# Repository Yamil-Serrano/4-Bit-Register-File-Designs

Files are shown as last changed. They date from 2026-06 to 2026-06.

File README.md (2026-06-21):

# 4-Bit Register File Designs

A collection of 4-bit register file implementations
exploring architectural trade-offs between
hardware minimalism and full register flexibility.
These designs demonstrate how storage, decoding,
and multiplexing interact inside a CPU register file
using discrete logic ICs and explicit wiring.

This repository includes two complete register file
architectures: a minimalist split-read design using
74HC157 multiplexers, and a fully flexible design
using 74HC153 multiplexers. Together, they show how
architectural decisions directly affect hardware
complexity, wiring density, and instruction freedom.

# Minimalist 4-Bit Register File (RB1574B – Split Read Architecture)

RB1574B represents a hardware-minimalist approach
to register file design. It is built entirely
from discrete logic ICs and focuses on reducing
the number of multiplexers required for register
selection while maintaining full write capability.

The architecture uses a split read model, where
each read port accesses a different subset of
registers. This limits some register-to-register
operations but significantly reduces hardware
complexity and control logic.

## Technical Specifications

### Core Features

* **Register Count**: 4 general-purpose registers
* **Register Width**: 4-bit parallel storage
* **Storage Type**: Edge-triggered D-type flip-flops
* **Read Ports**:

  * RS1: Register 1 or Register 2
  * RS2: Register 3 or Register 4
* **Write Port**: Single global RegWrite signal
* **Clocked Write**: Yes

## Integrated Circuits Used

| IC | Function | Quantity | Purpose |
| --- | --- | --- | --- |
| **74HC173** | 4-bit D-type Register | 4 | Register storage |
| **74HC157** | 2:1 Multiplexer | 2 | Read path selection |
| **74HC238** | 3-to-8 Decoder | 1 | Register write decoding |
| **74HC00**  | Quad NAND Gate | 1 | RegWrite gating logic |

## Hardware Implementation

### Circuit Design
Main

## Architecture Details

### Read Operation

* RS1 selects between Register 1 and Register 2
* RS2 selects between Register 3 and Register 4
* Registers within the same group cannot be read together
* Cross-group operations are supported

This split read structure mirrors constrained or
early CPU designs where hardware limitations
shape instruction-level flexibility.

### Write Operation

* A 74HC238 decoder selects one register
* NAND gates combine decoder outputs with RegWrite
* Only the selected register is enabled for writing
* Write access is fully flexible across all registers

### Breadboard Implementation


## Design Philosophy

RB1574B prioritizes simplicity and hardware efficiency.
By limiting read flexibility, the design reduces
chip count, wiring density, and control complexity.
This architecture demonstrates how physical hardware
constraints directly influence CPU behavior.

## Known Limitations

1. Not all register-to-register combinations are possible
2. RS1 and RS2 access disjoint register groups
3. Additional data movement instructions may be required

# Full 4-Bit Register File (RB1534B – Complete Read Architecture)

RB1534B represents a fully flexible register file implementation. Both read ports can independently access any register, enabling all possible register-to-register operations in hardware. This completeness comes at the cost of increased multiplexing logic, dense wiring, and higher visual complexity, especially in discrete IC designs.

### Core Features

- **Register Count**: 4 general-purpose registers
- **Register Width**: 4-bit parallel storage
- **Storage Type**: Edge-triggered D-type flip-flops
- **Read Ports**: Two fully independent read outputs
- **Write Port**: Single global RegWrite signal
- **Clocked Write**: Yes

### Integrated Circuits Used

| IC | Function | Quantity | Purpose |
| --- | --- | --- | --- |
| **74HC173** | 4-bit D-type Register | 4 | Register storage |
| **74HC153** | Dual 4:1 Multiplexer | 4 | Full read selection |
| **74HC238** | 3-to-8 Decoder | 1 | Register write decoding |
| **74HC00** | Quad NAND Gate | 1 | RegWrite gating logic |

**Total Components**: 10 ICs, implementing a complete 4-bit register file with full read/write flexibility.

## Hardware Implementation

### Circuit Design
Main_1

### PCB Design in KiCad


After validating the architecture in simulation, the design was migrated from breadboard to a custom PCB manufactured via JLCPCB. Each IC is paired with a dedicated 100nF ceramic bypass capacitor placed directly at the power pins to suppress switching noise. A 100µF bulk electrolytic capacitor stabilizes the 5V supply rail.

### Physical Build


## Verification & Test Bench

To validate correct operation across all possible register file states, a dedicated test bench was developed using an ESP32 microcontroller. The [`firmware`](./src/tester/src) exhaustively tests all register read/write combinations. Due to I/O pin limitations on the ESP32, the two read ports (RS1 and RS2) could not be tested simultaneously. Instead, a sequential verification strategy was employed:

- **RS1 Validation**: First, all register read/write combinations were exhaustively tested using Read Port 1 (RS1). Every possible write pattern (0–15) was written to each of the 4 registers, and RS1 independently selected each register to verify output correctness.
- **RS2 Validation**: After confirming 100% correct operation of RS1, the same test harness was reconfigured (pins reassigned) to validate Read Port 2 (RS2) identically.
- **Write Verification**: Writes a unique 4-bit pattern (0–15) to each of the 4 registers across multiple cycles.
- **Independence Test**: Verifies that writing to one register does not affect the contents of other registers.
- **RegWrite Gating**: Ensures that when RegWrite is low, no register state changes occur.

A total of 2,048 possible register file states (4 registers × 16 values × 16 read combinations for each port) were tested per read port, with both ports passing with 100% accuracy. Results are reported over Serial with ANSI color coding, distinguishing passing tests in green from failures in red. A 20×4 LCD display connected via I2C provides a real-time progress bar during testing and a summary screen upon completion.

### Operation Details

#### 1. **Register Write Operation**

- Write address decoded via 74HC238 3-to-8 decoder
- RegWrite signal gated with clock edge using 74HC00 NAND logic
- Data applied to all 74HC173 registers, but only selected register accepts new value on clock edge

#### 2. **Register Read Operation – Port 1 (RS1)**

- 2× 74HC153 multiplexers select any of the 4 registers
- 2-bit RS1 address selects which register appears on Read Data 1 bus

#### 3. **Register Read Operation – Port 2 (RS2)**

- Independent 2× 74HC153 multiplexer bank (separate from RS1)
- 2-bit RS2 address selects any register for Read Data 2 bus
- Both read ports operate simultaneously with zero contention

## Design Philosophy

RB1534B prioritizes architectural completeness over hardware simplicity. Every register selection is explicitly decoded and multiplexed, making this design ideal for studying scalable CPU register files and data-path construction.

## Comparative Summary

| Feature | RB1574B | RB1534B |
| --- | --- | --- |
| Read Flexibility | Limited (2×2) | Full (4×4) |
| Write Flexibility | Full | Full |
| Chip Count | Low | High |
| Wiring Density | Low | Very High |
| Educational Focus | Constraints | Completeness |

# FPGA Implementation: 4-Bit Register File (Tang Nano 9K)

This module implements a 4-bit register file on the Sipeed Tang Nano 9K FPGA, translating a discrete, flip-flop–based register file into a compact HDL description. The design faithfully recreates a classic hardware register file built from D flip-flops, a 2-to-4 decoder, and external multiplexers, preserving the original architectural intent while leveraging FPGA integration. The register file serves as a foundational storage element for a CPU-style datapath, providing controlled write access and multiple read paths suitable for ALU operand sourcing.

## Physical Prototype & Interfacing

To maintain a hands-on and educational workflow, the FPGA is interfaced with external switches and LEDs, closely mirroring the behavior and observability of the original discrete implementation.

**Input (Switches):**

* A 4-bit switch group provides *speculative ALU data*, allowing manual injection of values into the register file.
* Additional switches select the write register address and control the global write enable (`RegWrite`).
* All inputs use pull-down configurations to guarantee stable logic levels and avoid floating inputs.

**Output (LEDs):**

* Two independent 4-bit LED groups display the contents of the selected source registers (`rs1` and `rs2`).
* LEDs operate in an active-high configuration, where illumination represents a logic high (`1`).

This interface allows direct visual confirmation of register contents and write/read behavior in real time.

20251222\_233541
*Tang Nano 9K demonstrating manual register writes and LED-based readout.*

## Design Philosophy & Notes

* **Discrete-to-HDL Fidelity**: The register file was intentionally described using explicit registers, a decoder, and multiplexers to mirror the original TTL-based design (e.g., 74HC238 for decoding and 74HC157 for selection), rather than relying on abstract HDL shortcuts.
* **Educational Transparency**: Each register is represented explicitly, making the data flow and control logic easy to trace and reason about, especially for learners transitioning from breadboard-based designs to HDL.
* **Controlled Write Semantics**: A global write enable combined with a decoded register select ensures that exactly one register captures data on a rising clock edge, replicating real-world register file behavior.
* **Modular Expansion**: Exposing individual register outputs enables flexible experimentation, such as external multiplexing, debugging, or future ALU integration.

## Comparative Summary: Discrete vs. FPGA Register File

| Aspect | Discrete IC Implementation | FPGA Implementation |
| :--- | :--- | :--- |
| **Component Count**  | Multiple flip-flops, decoder, and multiplexers. | **1** FPGA device. |
| **Storage Elements** | Individual 74HC173 wired by hand. | Synthesized registers from HDL. |
| **Address Decoding** | Physical 74HC238 decoder IC. | Behavioral decoder logic. |
| **Read Selection** | External multiplexers (e.g., 74HC157). | Combinational HDL multiplexing. |
| **Flexibility** | Fixed wiring; modifications require rewiring. | **Reconfigurable** via HDL changes. |
| **Learning Focus** | Understanding register-level hardware construction. | Bridging discrete logic concepts into FPGA-based design. |

### Historical Note:

While working on this design, I later discovered the 74HC670, a single IC that could implement a full 4-bit register file with all read/write flexibility. At that point, I had already spent around $35 on multiple ICs (157s, 153s, 173s, etc.) to build the RB157 and RB153 designs, while the 74HC670 costs around $10. However, building the register files with discrete components first gave me deep insight into MUX cascading, RegWrite logic, and architectural limitations.

Reflection: If I had bought the 74HC670 from the start:

* I would not have understood MUX cascades
* I would not have understood RegWrite
* I would not have seen real limitations
* The chip would have been a black box

With $10 you could buy a fully functional chip. With $35, you bought deep understanding and hands-on experience.

## License

Licensed under the **Solderpad Hardware License v2.1**.
See the [LICENSE](LICENSE-HARDWARE) file for full terms.

## Contact

If you have any questions or suggestions, feel free to reach out:

* **GitHub:** [Neowizen](https://github.com/Yamil-Serrano)

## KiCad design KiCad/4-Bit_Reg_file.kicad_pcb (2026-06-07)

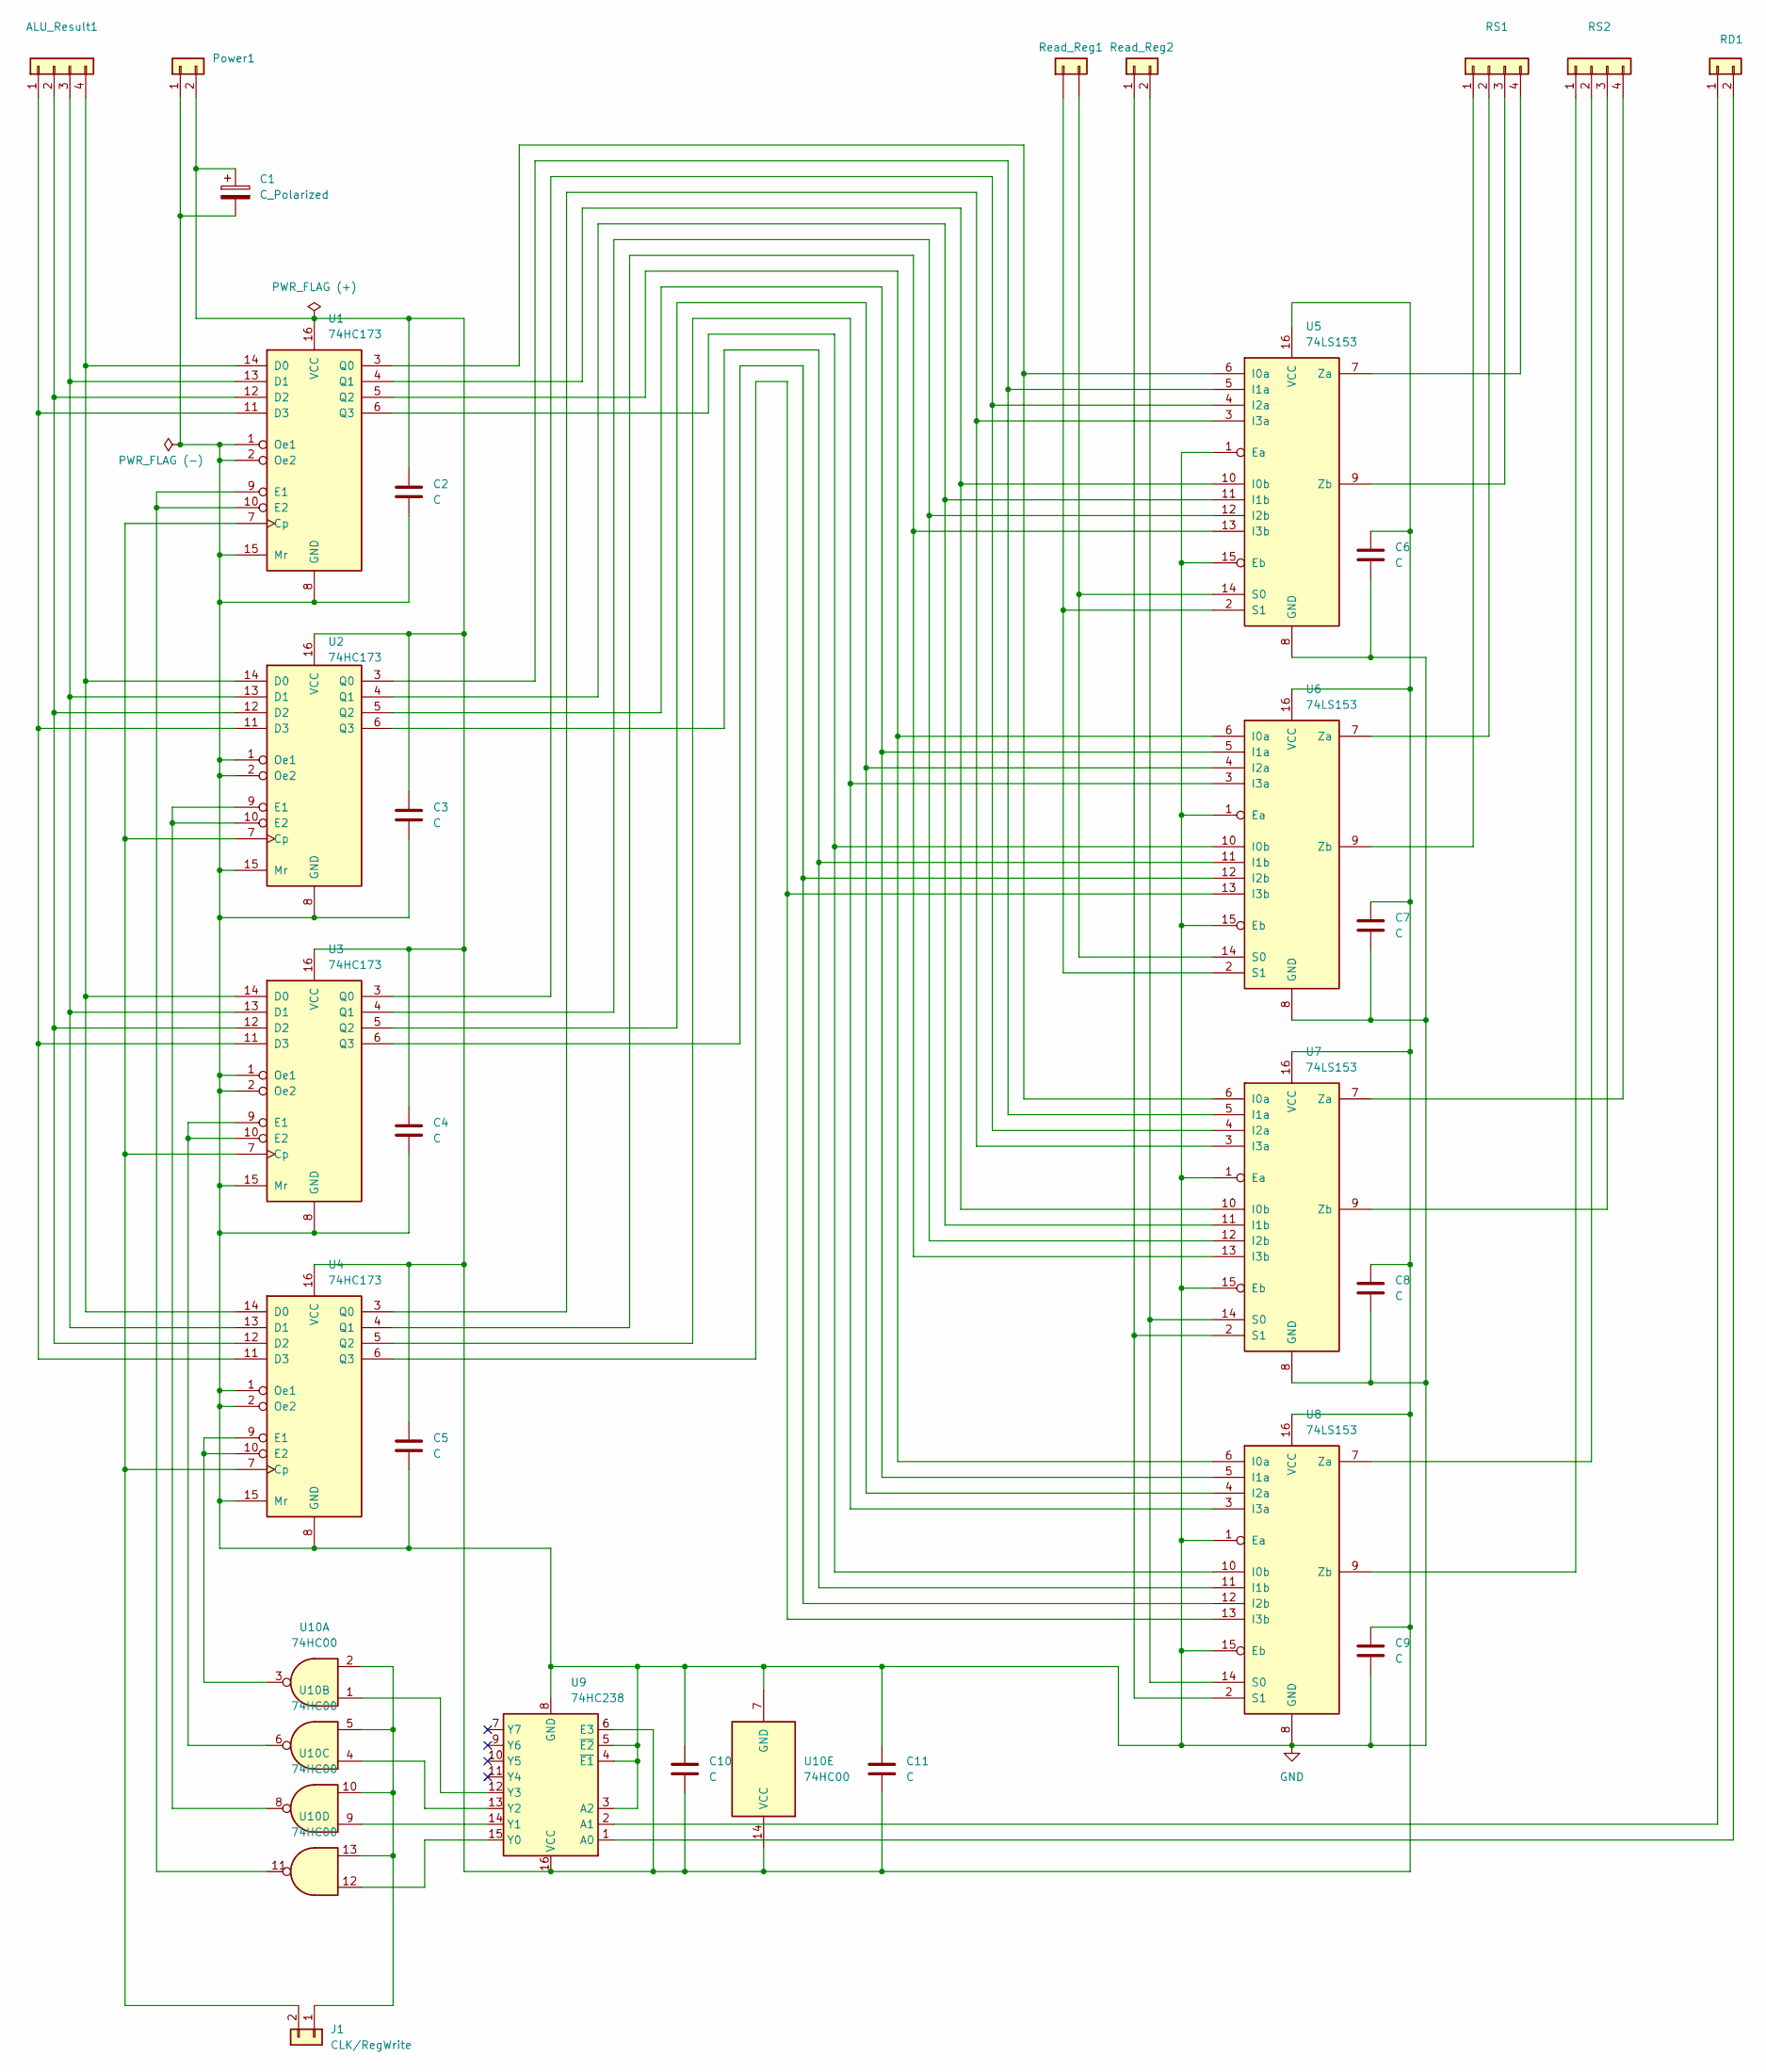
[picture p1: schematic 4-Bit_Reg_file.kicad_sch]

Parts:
ALU_Result1: Conn_01x04; PinHeader_1x04_P2.54mm_Vertical
C1: C_Polarized; CP_Radial_D4.0mm_P1.50mm
C2, C3, C4, C5, C6, C7, C8, C9, C10, C11: C; C_Disc_D3.0mm_W1.6mm_P2.50mm
J1: CLK/RegWrite; PinHeader_1x02_P2.54mm_Vertical
Power1: Conn_01x02; PinHeader_1x02_P2.54mm_Vertical
RD1: Conn_01x02; PinHeader_1x02_P2.54mm_Vertical
RS1, RS2: Conn_01x04; PinHeader_1x04_P2.54mm_Vertical
Read_Reg1, Read_Reg2: Conn_01x02; PinHeader_1x02_P2.54mm_Vertical
U1, U2, U3, U4: 74HC173; DIP-16_W7.62mm_Socket
U5, U6, U7, U8: 74LS153; DIP-16_W7.62mm_Socket
U9: 74HC238; DIP-16_W7.62mm_Socket
U10: 74HC00; DIP-14_W7.62mm_Socket

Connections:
GND: C1.2, C2.2, C3.2, C4.2, C5.2, C6.2, C7.2, C8.2, C9.2, C10.1, C11.1, Power1.1, U1.1 (Oe1), U1.2 (Oe2), U1.8 (GND), U1.15 (Mr), U2.1 (Oe1), U2.2 (Oe2), U2.8 (GND), U2.15 (Mr), U3.1 (Oe1), U3.2 (Oe2), U3.8 (GND), U3.15 (Mr), U4.1 (Oe1), U4.2 (Oe2), U4.8 (GND), U4.15 (Mr), U5.1 (Ea), U5.8 (GND), U5.15 (Eb), U6.1 (Ea), U6.8 (GND), U6.15 (Eb), U7.1 (Ea), U7.8 (GND), U7.15 (Eb), U8.1 (Ea), U8.8 (GND), U8.15 (Eb), U9.3 (A2), U9.4 (~E1), U9.5 (~E2), U9.8 (GND), U10.7 (GND)
unnamed: ALU_Result1.1, U1.11 (D3), U2.11 (D3), U3.11 (D3), U4.11 (D3)
unnamed: ALU_Result1.2, U1.12 (D2), U2.12 (D2), U3.12 (D2), U4.12 (D2)
unnamed: ALU_Result1.3, U1.13 (D1), U2.13 (D1), U3.13 (D1), U4.13 (D1)
unnamed: ALU_Result1.4, U1.14 (D0), U2.14 (D0), U3.14 (D0), U4.14 (D0)
unnamed: J1.1, U10.2, U10.5, U10.10, U10.13
unnamed: J1.2, U1.7 (Cp), U2.7 (Cp), U3.7 (Cp), U4.7 (Cp)
unnamed: C1.1, C2.1, C3.1, C4.1, C5.1, C6.1, C7.1, C8.1, C9.1, C10.2, C11.2, Power1.2, U1.16 (VCC), U2.16 (VCC), U3.16 (VCC), U4.16 (VCC), U5.16 (VCC), U6.16 (VCC), U7.16 (VCC), U8.16 (VCC), U9.6 (E3), U9.16 (VCC), U10.14 (VCC)
unnamed: RD1.1, U9.2 (A1)
unnamed: RD1.2, U9.1 (A0)
unnamed: RS1.1, U6.9 (Zb)
unnamed: RS1.2, U6.7 (Za)
unnamed: RS1.3, U5.9 (Zb)
unnamed: RS1.4, U5.7 (Za)
unnamed: RS2.1, U8.9 (Zb)
unnamed: RS2.2, U8.7 (Za)
unnamed: RS2.3, U7.9 (Zb)
unnamed: RS2.4, U7.7 (Za)
unnamed: Read_Reg1.1, U5.2 (S1), U6.2 (S1)
unnamed: Read_Reg1.2, U5.14 (S0), U6.14 (S0)
unnamed: Read_Reg2.1, U7.2 (S1), U8.2 (S1)
unnamed: Read_Reg2.2, U7.14 (S0), U8.14 (S0)
unnamed: U1.9 (E1), U1.10 (E2), U10.11
unnamed: U1.3 (Q0), U5.6 (I0a), U7.6 (I0a)
unnamed: U1.4 (Q1), U5.10 (I0b), U7.10 (I0b)
unnamed: U1.5 (Q2), U6.6 (I0a), U8.6 (I0a)
unnamed: U1.6 (Q3), U6.10 (I0b), U8.10 (I0b)
unnamed: U2.9 (E1), U2.10 (E2), U10.8
unnamed: U2.3 (Q0), U5.5 (I1a), U7.5 (I1a)
unnamed: U2.4 (Q1), U5.11 (I1b), U7.11 (I1b)
unnamed: U2.5 (Q2), U6.5 (I1a), U8.5 (I1a)
unnamed: U2.6 (Q3), U6.11 (I1b), U8.11 (I1b)
unnamed: U3.9 (E1), U3.10 (E2), U10.6
unnamed: U3.3 (Q0), U5.4 (I2a), U7.4 (I2a)
unnamed: U3.4 (Q1), U5.12 (I2b), U7.12 (I2b)
unnamed: U3.5 (Q2), U6.4 (I2a), U8.4 (I2a)
unnamed: U3.6 (Q3), U6.12 (I2b), U8.12 (I2b)
unnamed: U4.9 (E1), U4.10 (E2), U10.3
unnamed: U4.3 (Q0), U5.3 (I3a), U7.3 (I3a)
unnamed: U4.4 (Q1), U5.13 (I3b), U7.13 (I3b)
unnamed: U4.5 (Q2), U6.3 (I3a), U8.3 (I3a)
unnamed: U4.6 (Q3), U6.13 (I3b), U8.13 (I3b)
unnamed: U9.15 (Y0), U10.12
unnamed: U9.14 (Y1), U10.9
unnamed: U9.13 (Y2), U10.4
unnamed: U9.12 (Y3), U10.1

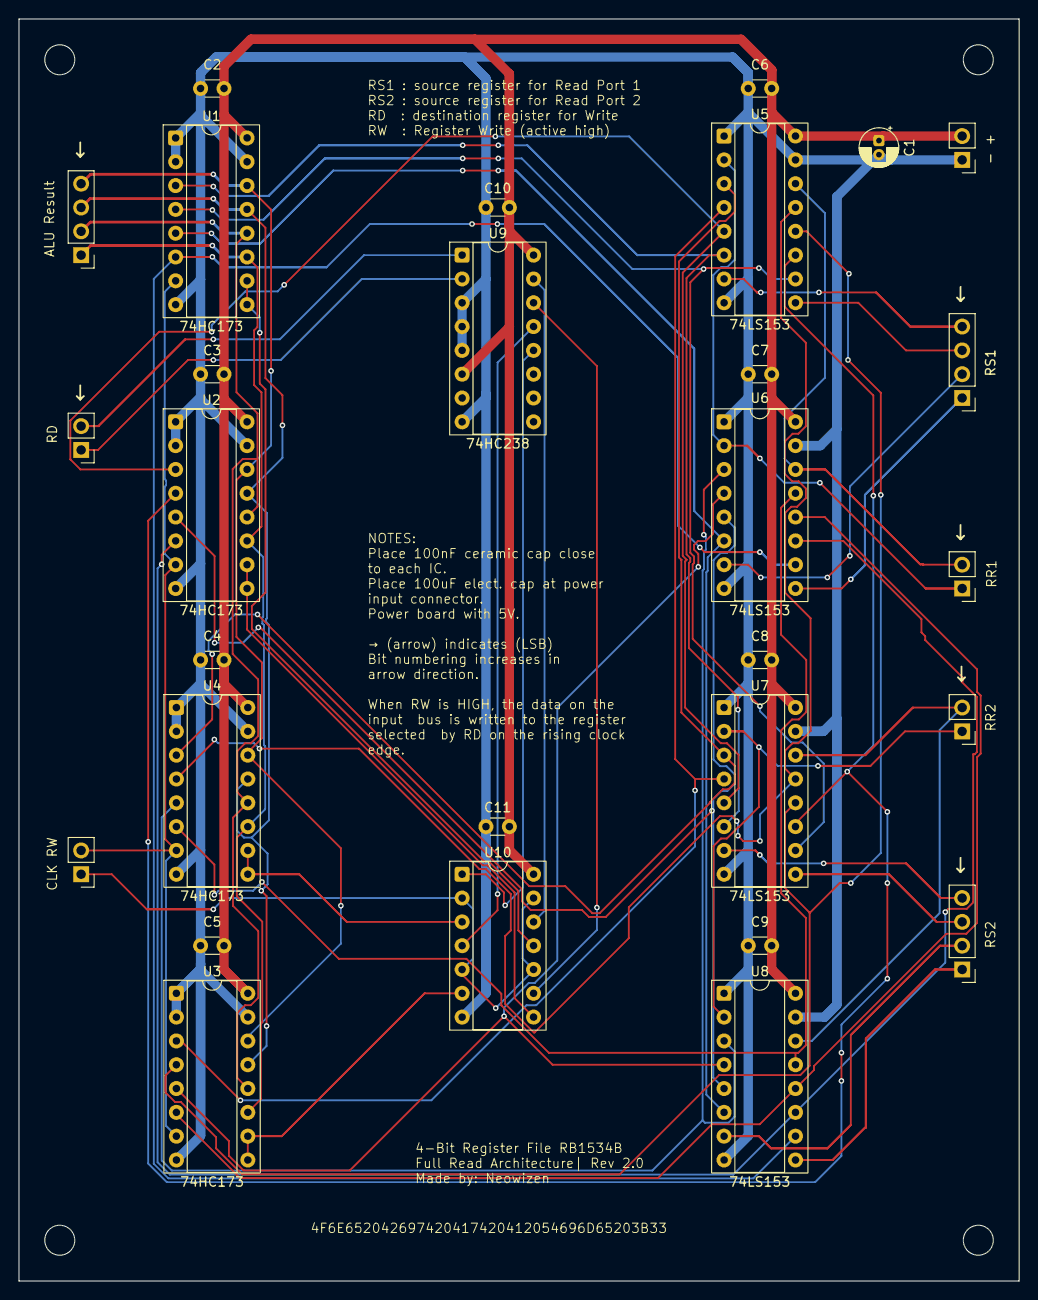
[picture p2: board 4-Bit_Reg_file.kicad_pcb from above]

Board: 2 copper layers, 106.7 x 134.6 mm, 29 parts (0 on the bottom side), 46 nets.

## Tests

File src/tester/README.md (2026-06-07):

# 4-Bit ALU Tester for ESP32

## Upload Instructions

### Windows
Just upload your code. That's it. No additional configuration needed.

### Linux
**One-time setup (do this once):**

1. Run: sudo usermod -a -G dialout $USER
2. Restart your computer

**After setup:** upload normally with pio run --target upload

## Monitor Output
Run: pio device monitor
Press Ctrl + C to exit.

## Folder Structure
Your .cpp file must be inside the src/ folder.

## Common Errors
- **"Permission denied: /dev/ttyUSB0" on Linux** → You skipped the one-time setup. Add yourself to dialout group and restart.

- **"undefined reference to setup/loop"** → Your main .cpp file is not in the src/ folder.

- **Upload stuck at "Connecting..."** → Hold the BOOT button on your ESP32 during upload.

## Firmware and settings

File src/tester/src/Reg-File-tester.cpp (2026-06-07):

#include <Arduino.h>
#include <Wire.h>
#include <LiquidCrystal_I2C.h>

// Exhaustive write/read test on all 4 registers (0-15 each)
// Follow your Reg File design and pinout to update these arrays if needed 
// Current pin setup assumes 4-Bit Register File RB1534B Rev 2.0

// Data Input [LSB -> MSB]
const int PIN_DATAIN[] = {15, 2, 4, 16};

// Write Register Select (RD) [LSB -> MSB]
const int PIN_RD[] = {17, 5};

// Read Register Select (RR1) [LSB -> MSB]
const int PIN_RR1[] = {18, 19};

// Control Signals
const int PIN_CLOCK    = 22;
const int PIN_REGWRITE = 23;

// Register Output RS1 [LSB -> MSB]
const int PIN_RS1[] = {14, 27, 26, 25};

// LCD I2C pins
const int I2C_SDA = 33;
const int I2C_SCL = 32;

LiquidCrystal_I2C lcd(0x27, 20, 4);

#define ANSI_GREEN  "\033[32m"
#define ANSI_RED    "\033[31m"
#define ANSI_YELLOW "\033[33m"
#define ANSI_CYAN   "\033[36m"
#define ANSI_RESET  "\033[0m"

void printDivider() {
    Serial.println("------------------------------------------------------------");
}

void setDataIn(byte value) {
    for (int i = 0; i < 4; i++)
        digitalWrite(PIN_DATAIN[i], bitRead(value, i));
}

void setRD(byte reg) {
    for (int i = 0; i < 2; i++)
        digitalWrite(PIN_RD[i], bitRead(reg, i));
}

void setRR1(byte reg) {
    for (int i = 0; i < 2; i++)
        digitalWrite(PIN_RR1[i], bitRead(reg, i));
}

void pulseClock() {
    digitalWrite(PIN_CLOCK, LOW);
    delayMicroseconds(5);
    digitalWrite(PIN_CLOCK, HIGH);
    delayMicroseconds(10);
    digitalWrite(PIN_CLOCK, LOW);
    delayMicroseconds(5);
}

byte readRS1() {
    byte value = 0;
    for (int i = 0; i < 4; i++)
        if (digitalRead(PIN_RS1[i]))
            value |= (1 << i);
    return value;
}

void writeRegister(byte reg, byte value) {
    setDataIn(value);
    setRD(reg);
    digitalWrite(PIN_REGWRITE, HIGH);
    delayMicroseconds(5);
    pulseClock();
    delayMicroseconds(10);
    digitalWrite(PIN_REGWRITE, LOW);
}

byte readRegister(byte reg) {
    setRR1(reg);
    delayMicroseconds(10);
    return readRS1();
}

void printBin4(byte val) {
    Serial.print("0b");
    for (int i = 3; i >= 0; i--)
        Serial.print((val >> i) & 1);
}

//  Unique Pattern Test — isolates read-path decoder
bool runUniquePatternTest() {
    Serial.println();
    printDivider();
    Serial.println("                  UNIQUE PATTERN TEST");
    printDivider();
    Serial.println("  Reg  |  Written   |  Read      |  Result");
    printDivider();

    const byte patterns[4] = { 0x1, 0x2, 0x4, 0x8 };

    for (byte reg = 0; reg < 4; reg++)
        writeRegister(reg, patterns[reg]);

    bool allPass = true;

    for (byte reg = 0; reg < 4; reg++) {
        byte observed = readRegister(reg);
        bool ok = (observed == patterns[reg]);
        if (!ok) allPass = false;

        Serial.print("  R"); Serial.print(reg);
        Serial.print("   |  ");
        printBin4(patterns[reg]);
        Serial.print("  |  ");
        printBin4(observed);
        Serial.print("  |  ");
        if (ok) {
            Serial.print(ANSI_GREEN); Serial.println("PASS");
        } else {
            Serial.print(ANSI_RED); Serial.println("FAIL");
        }
        Serial.print(ANSI_RESET);
    }
    printDivider();
    return allPass;
}

//  Exhaustive Test — all 16 values per register
struct RegResult {
    int hits;
    int total;
    float pct;
};

RegResult regResults[4];

void runExhaustiveTest() {
    Serial.println();
    printDivider();
    Serial.println("                 EXHAUSTIVE REGISTER TEST");
    printDivider();

    int totalFails = 0;

    for (byte reg = 0; reg < 4; reg++) {
        int hits = 0;

        Serial.println();
        Serial.print("  [R"); Serial.print(reg); Serial.println("]");
        Serial.println("  Write      | Read       | Result");
        Serial.println("  --------------------------------");

        for (byte val = 0; val < 16; val++) {
            writeRegister(reg, val);
            byte observed = readRegister(reg);
            bool ok = (observed == val);
            if (ok) hits++;
            else totalFails++;

            Serial.print("  "); printBin4(val);
            Serial.print(" ("); Serial.print(val); Serial.print(")  | ");
            printBin4(observed);
            Serial.print(" ("); Serial.print(observed); Serial.print(")  | ");
            if (ok) {
                Serial.print(ANSI_GREEN); Serial.println("HIT");
            } else {
                Serial.print(ANSI_RED); Serial.println("MISS");
            }
            Serial.print(ANSI_RESET);
        }

        regResults[reg] = { hits, 16, (hits * 100.0f) / 16 };

        Serial.print("  Result: ");
        if (regResults[reg].pct == 100.0f) Serial.print(ANSI_GREEN);
        else Serial.print(ANSI_YELLOW);
        Serial.print(hits); Serial.print("/16 (");
        Serial.print(regResults[reg].pct, 1); Serial.println("%)");
        Serial.print(ANSI_RESET);
    }

    // Summary table
    Serial.println();
    printDivider();
    Serial.println("                  REGISTER FILE SUMMARY");
    printDivider();
    Serial.println("  Reg  |  RD bits  |  Hits   |  Pass Rate");
    printDivider();

    for (int r = 0; r < 4; r++) {
        int b1 = (r >> 1) & 1, b0 = r & 1;
        Serial.print("  R"); Serial.print(r);
        Serial.print("   |   "); Serial.print(b1); Serial.print(" "); Serial.print(b0);
        Serial.print("     |  ");
        Serial.print(regResults[r].hits); Serial.print("/16  |  ");
        if (regResults[r].pct == 100.0f) Serial.print(ANSI_GREEN);
        else Serial.print(ANSI_YELLOW);
        Serial.print(regResults[r].pct, 1); Serial.println("%");
        Serial.print(ANSI_RESET);
    }
    printDivider();

    Serial.println("\n  [PASS] 100% match:");
    for (int r = 0; r < 4; r++)
        if (regResults[r].pct == 100.0f) {
            Serial.print("    R"); Serial.print(r);
            Serial.print(" -> "); Serial.print(ANSI_GREEN);
            Serial.println("PASS"); Serial.print(ANSI_RESET);
        }

    bool anyWarn = false;
    for (int r = 0; r < 4; r++)
        if (regResults[r].pct < 100.0f && regResults[r].pct > 0) { anyWarn = true; break; }

    Serial.print("\n  [");
    Serial.print(ANSI_YELLOW); Serial.print("WARNING"); Serial.print(ANSI_RESET);
    Serial.println("] Partial match:");
    if (!anyWarn) {
        Serial.print("    "); Serial.print(ANSI_GREEN);
        Serial.println("None"); Serial.println(ANSI_RESET);
    } else {
        for (int r = 0; r < 4; r++)
            if (regResults[r].pct < 100.0f && regResults[r].pct > 0) {
                Serial.print("    R"); Serial.print(r); Serial.print(" -> (");
                Serial.print(ANSI_YELLOW); Serial.print(regResults[r].pct, 1);
                Serial.print("%"); Serial.print(ANSI_RESET); Serial.println(")");
            }
    }

    Serial.println();
    printDivider();
    if (totalFails == 0) {
        Serial.print(ANSI_GREEN);
        Serial.println("         REGISTER FILE TEST COMPLETE — PASS");
    } else {
        Serial.print(ANSI_RED);
        Serial.print("         REGISTER FILE TEST COMPLETE — ");
        Serial.print(totalFails); Serial.println(" FAILURE(S)");
    }
    Serial.print(ANSI_RESET);
    printDivider();
}

// Function to update progress bar on LCD
void updateProgressBar(int currentStep, int totalSteps) {
    int progress = map(currentStep, 0, totalSteps, 1, 18);
    for (int i = 1; i <= 18; i++) {
        lcd.setCursor(i, 2);
        if (i <= progress) {
            lcd.print((char)255);  // Block character for progress
        } else {
            lcd.print(" ");  // Clear remaining
        }
    }
}

//  Setup
void setup() {
    delay(1000);
    Serial.begin(9600);

    // Initialize I2C with custom pins
    Wire.begin(I2C_SDA, I2C_SCL);
    
    // Initialize LCD
    lcd.init();
    lcd.backlight();
    lcd.clear();
    
    // LCD Boot Screen with progress bar
    lcd.setCursor(0, 0);
    lcd.print("   Hardware Bench");
    lcd.setCursor(0, 1);
    lcd.print("   Initializing");
    lcd.setCursor(0, 3);
    lcd.print(" Made by: Neowizen");
    
    // Initial progress bar (empty)
    for (int i = 1; i <= 18; i++) {
        lcd.setCursor(i, 2);
        lcd.print(" ");
    }
    
    // Animate progress bar during initialization
    for (int step = 1; step <= 18; step++) {
        updateProgressBar(step, 18);
        delay(50);  // Smooth animation
    }
    
    delay(500);  // Show full progress bar briefly

    // Setup pins
    for (int i = 0; i < 4; i++)
        pinMode(PIN_DATAIN[i], OUTPUT);
    for (int i = 0; i < 2; i++) {
        pinMode(PIN_RD[i],  OUTPUT);
        pinMode(PIN_RR1[i], OUTPUT);
    }
    pinMode(PIN_CLOCK,    OUTPUT);
    pinMode(PIN_REGWRITE, OUTPUT);
    for (int i = 0; i < 4; i++)
        pinMode(PIN_RS1[i], INPUT);

    digitalWrite(PIN_CLOCK,    LOW);
    digitalWrite(PIN_REGWRITE, LOW);

    delay(500);

    Serial.println("\n");
    printDivider();
    Serial.println("              4-BIT REGISTER FILE TESTER");
    printDivider();

    // Run Unique Pattern Test
    Serial.println("\nRunning Unique Pattern Test...");
    runUniquePatternTest();
    
    // Run Exhaustive Test
    runExhaustiveTest();
    
    // Calculate final average for LCD
    float totalPct = 0.0f;
    for (int r = 0; r < 4; r++) {
        totalPct += regResults[r].pct;
    }
    float avgPct = totalPct / 4.0f;
    
    // Count perfect registers
    int perfect = 0;
    for (int r = 0; r < 4; r++) {
        if (regResults[r].pct == 100.0f)
            perfect++;
    }
    
    // LCD Final Report
    lcd.clear();
    lcd.setCursor(0, 0);
    lcd.print("   TEST COMPLETED");
    lcd.setCursor(0, 1);
    lcd.print("   Result: ");
    lcd.print(avgPct, 1);
    lcd.print("%");
    lcd.setCursor(0, 2);
    lcd.print(" More bench details");
    lcd.setCursor(0, 3);
    lcd.print(" in Serial Terminal");
}

void loop() { 
    delay(200); 
}

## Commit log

2025-12-21 Add Solderpad Hardware License v2.1
2026-01-07 Replace circuit design images with new versions
    Updated circuit design images in the README.
2026-05-21 Update circuit image and modify write operation details
    Updated image in Circuit Design section and removed a line in Write Operation section.
2026-06-07 Revise README for clarity and structure
    Updated README to improve clarity and organization of content, including circuit design images and detailed architecture descriptions.
2026-06-07 Add 4-Bit Reg file KiCad project
    [4-Bit_Reg_file.kicad_pcb, 4-Bit_Reg_file.kicad_sch]
2026-06-14 Title block added to schematic
    [4-Bit_Reg_file.kicad_sch]
2026-06-21 Update circuit design image in README.md
